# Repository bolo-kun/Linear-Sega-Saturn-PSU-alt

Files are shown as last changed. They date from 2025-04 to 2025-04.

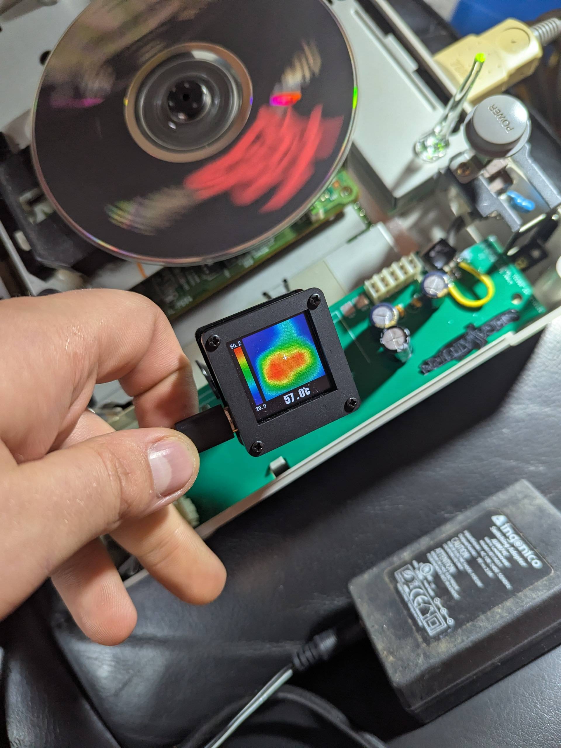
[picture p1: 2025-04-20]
images/temperature_test.jpg

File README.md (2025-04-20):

# Update
I've tested the original design, now waiting for my revised PCB to test it out.<br>
BL1084-33CS1 looks to be the easy to get 3.3v regulator but the pinout is slightly different so I'v added in 4th pad to accommodate both pinouts<br>
That huge radiator is a pure waste or money, I've used what I had at hand and the temperatures did not even exceed 60C. You could looks for either large-ish TO-220 radiator or easier yet, try to fit some generic TO-247 radiator, as they are a bit more bulky.<br>
Since pretty much every game console uses 9V, positive-center power supplies, I've replaced the diode with a bridge so that ay generic or console standard DC adapter can be used.
<br><br>
I'll update the README later on, for now it's just a lazy comment.
<br><br>
TODO:<br>
Test revised PCB<br>
Test the design on top-mounted PSU saturns - other than having to stick the board with a tape I see no reason why it wouldn't work<br>
Make a small PCB for early and late Saturns<br>
Make a propper README<br>

# for now just 1:1 forked copy, I'll slowly work on my changes when I get parts and have it tested
Since half of the parts used in the OG design are pretty much unoptanium I'll replace the components that are no longer available with some more generic, easily available parts

# Linear-Sega-Saturn-Power-Supply
<br>
A super clean Sega Saturn PSU for VA-SG  / VA-SD mainboards found in rev2 (white) Saturns.
<br>
<br>

## Table Of Contents

<br>

[Components](#Components) <br>
[Usage](#Usage) <br>
[Description](#Description) <br>
[Installs](#Installs) <br>
[Compatibility](#Compatibility) <br>

<br>
<br>
      
## Components
<br>

 <br>
H0669 Heatsink<br>
<br>
<br>

 <br>
Generic 2.1mm Bulkhead Male DC Power Connector <br>
I had someone custom print me the plastic mounting part for fitment into the saturn
<br>
<br>

 <br>
digikey P/N A106608-ND (or re-use the one off the factory PSU) <br>
<br>
<br>

 <br>
Mouser P/N 09-48--4059 (or re-use the one off the factory PSU) <br>
<br>
<br>

Diode * 1

* 1N5822 Schottky 40V 3A DO-27

Regulators

* Texas Instruments LM1084IT-5.0
* Microchip MIC2940A-3.3WU LDOI 3.3v / 3-Pin, D2PAK (TO-263)

Capacitors (Go high quality! Wurth, kemet etc.)

* Input (shared): 100uf 35v
* Smoothing: 220uf 25v * 2
* High Freq filter: 0.1uf 50v * 2
<br>
<br>

Power Supply

* Any high quality 9v supply, at least 2A output. I use the M8925D, but others will suffice.
      
## Usage
<br>

* This is a replica of the factory PSU in regards to the PCB shape. It will fit like a factory supply and the heatsink clears the top shell.<br>
<br>

* The jumper is for users wanting to use the disc drive rather than an ODE. It's a safety guard because you might be using a 12v supply.
This is not recommended, it generates more heat for the linear regulators to dissipate. The 3.3v reg usually won't even  get luke warm but the 5v regulator
will however generate needless heat.  Second to this, the disc drive wants the 9v supply to operate. I wouldn't risk running it at 12v, it probably has it's
own step down regulator but its run at 9v from factory. The DIODE will drop the 9v input down to about 8.5v to 8.6v. The disc drive circuit is happy with this.
<br>
<br>

## Description

I've sold quite a few pre-modded systems with these, and the supplies on their own. 100% happy customers. I will continue to sell them but decided to open source the project. It's a simple design, it works well, you won't find a cleaner supply. This was tested under the scope. It is quite literally, on average, about 10x cleaner than the switching supplies out there. I added the CD drive track/ jumper before uploading the design as I've had to instruct a few people on how to run a bodge wire. The saturn documents out there won't tell you that you need that line, but it definitely operates the disc drive on these particular revisions of board.

## Installs

 <br>
With original fenrir ODE (Before the 20/21pin became a single board) <br>
<br>
<br>

 <br>
With original fenrir ODE (Before the 20/21pin became a single board) <br>
<br>
<br>

 <br>
Custom fully recapped saturn with clear shell,  FRAM and MODE ODE, utilising the external 5v pads on the PSU to power the MODE<br>
<br>
<br>

## Compatibility
